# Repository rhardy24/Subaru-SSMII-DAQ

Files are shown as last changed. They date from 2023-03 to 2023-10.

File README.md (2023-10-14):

# Subaru-SSMII-DAQ
A Teensy 4.1 project, interfacing with the SSM Protocol in K-Line based Subarus through the OBD2 port to acquire engine sensor data, display on a TFT LCD, and log to an SD Card

Code is built and uploaded using VSCode and PlatformIO. It currently uses the Arduino framework.

Currently a work in progress

# Overview
In 2008, CAN bus based ISO 15765-4 became stadardized to be used for on-board diagnostics (OBD) in all new vehicles. Prior to this, manufacturers used varying communication protocols and layers for OBD. 

The vehicle this project was designed around is a 2006 Subaru Legacy 2.5i Limited with an EJ253 engine and 4EAT automatic transmission. Although it can vary based of model and region, Subaru's made between 2000 - 2007 used the Subaru Select Monitor II protocol over K-Line (ISO 9141) over the OBD port to communicate with and diagnose the vehicles ECUs. 

Following one of the famous head gasket failures that Subaru's are known for, a method to monitor and log engine sensor data was desired. Thus, this project began.

# Major Components Used
- Teensy 4.1 as the MCU
- Onboard SD slot with SDIO
- Onboard RTC
- [SN65HVDA195QDRQ1 LIN Transceiver](https://www.digikey.ca/en/products/detail/texas-instruments/SN65HVDA195QDRQ1/2094636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)
- [Adafruit 2.8" Capacitive Touchscreen TFT Display](https://www.digikey.ca/en/products/detail/adafruit-industries-llc/2090/9919535)
- [CR2032 Battery Holder](https://www.digikey.ca/en/products/detail/adafruit-industries-llc/1870/6827145) for the RTC
- [Sparkfun OBD2 to DB9 cable](https://www.digikey.ca/en/products/detail/sparkfun-electronics/CAB-10087/5721422)

# Development Notes
Originally, this project was planned to use a Raspberry Pi RP2040 Pico as the MCU, yet after initial testing, it was found that the processor was too slow to achieve a desireable refresh rate on the TFT display. Addionally, there were compatibility issues encountered when testing existing libraries for the TFT display, SD card reader over SPI, and others. With the significantly faster processor, onboard SD and RTC, and broader IO capabilities of the Teensy 4.1, it was chosen as the replacement, with much improved results. 

One issue faced with the Teensy 4.1 was regarding its voltage input. A criteria of the design was to be able to safely plug in / unplug a laptop from the Teensy while it was being powered from the vehicle. There were concerns with shorts when having two devices powering the 5V pin of the Teensy, as it has no on-board circuitry to isolate VUSB from the 5V VIN pin. To solve this, the VUSB jumper on the bottom of the Teensy was cut, which disconnects VUSB from the VIN pin. A female header was soldered to the inboard VUSB through-hole, and a diode was placed between the VUSB pin and VIN. This way, both the laptop and vehicle power coud be connected to the circuit safely. If just the laptop was connected, there would be a small voltage drop across the diode, making the voltage at the VIN pin around 4.3V. When the device was plugged into the vehicle, the LDO would provide 5V to the VIN pin, and no backfeeding would occur between the sources, thanks to the diode. 

## Bugs/To-Dos
- [x] Improve Data receive rate: When requesting ECU data in the single response mode, data would only be received at ~1Hz, which is far less than desireable for fast changing data like engine RPM, timing, MAP, etc. Solved by using the 'respond until interrupted' mode (byte 5 as 0x01 instead of 0x00), and improving efficiency of functions.
- [ ] 12V Supply: The 12V pin on the OBD2 port is always on (KL30), but an ignition power source (KL15) would be more desireable to eliminate the battery draw if the device is left plugged in when the vehicle is off. Need to find a source of switched power to use (while keeping the wiring clean), simply add a power switch that would need to be turned on/off manually with the vehicle ignition, or implement a software sleep state.
- [ ] 5V Regulator: A 7805 LDO (linear dropout) voltage regulator was used to get 5V power for the device, but the large voltage drop across the LDO is undesireable for efficiency and heat. Using a switching regulator circuit in a future iteration would be more desireable, but not mandatory.
- [ ] Log file name with date/time: Incorporate the date/time that the Teensy became powered into the log file name to ensure logs aren't overwritten. This was initially attempted by concatenating Strings into the file name, but caused the Teensy to crash. Also, add date/time back into outputHeaders / outputValues functions
- [ ] Add multiple screens: Use the touchscreen to toggle through multiple screens/gauge layouts. The display is too small to show all of the received data at once, thus multiple display layouts would be nice.
- [ ] Add TCU communication: It would be nice to get information from the transmission controller (TCU), but this is not described in ROMRaider. Research what could be requested from the TCU, and figure out if it is worth sacrificing ECU data rate for.
- [ ] Write script to convert csv data to MoTeC i2 log files: MoTeC i2 is an industry used data viewing software, typically used with MoTeC Motorsport ECUs. Is it possible to convert data into the MoTeC file types to view in i2? Would durastically improve the viewing experience of the logs.
- [ ] Move to an RTOS. Both for the learning, and for proper scheduling and timing of the program, using an RTOS over the Arduino Framework would be a welcomed upgrade to the project.

# References
- Original inspiration for the project: [Obesiance's Clock-pod mod with SSM](https://www.clubwrx.net/threads/clock-pod-mod-with-subarb-select-monitor-ecu-polling-and-arduino.134423369/)
- [RomRaider wiki](https://www.romraider.com/RomRaider/SsmProtocol)
- [rpkish's Subduino-SSM](https://github.com/rpkish/Subduino-SSM)
- [matprophet's subduino](https://github.com/matprophet/subduino)
- [Magister54's opengauge](https://github.com/magister54/opengauge)
- [KrisKasprzak's GraphingFunction](https://github.com/KrisKasprzak/GraphingFunction)

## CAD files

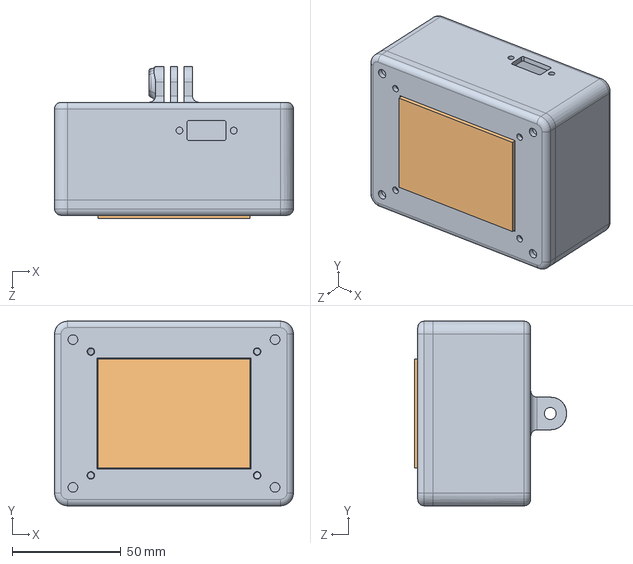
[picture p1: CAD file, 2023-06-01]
CAD-Files/A-001-Top-Level-DAQ.SLDASM
110.0 x 85.0 x 70.0 mm
C-002-Enclosure x 2

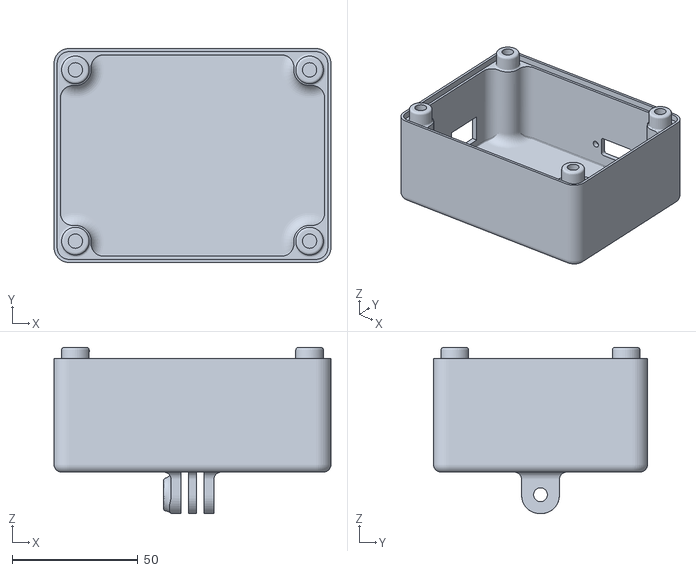
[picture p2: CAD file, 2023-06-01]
CAD-Files/C-002-Enclosure-Bottom-V2.STL
110.0 x 85.0 x 66.0

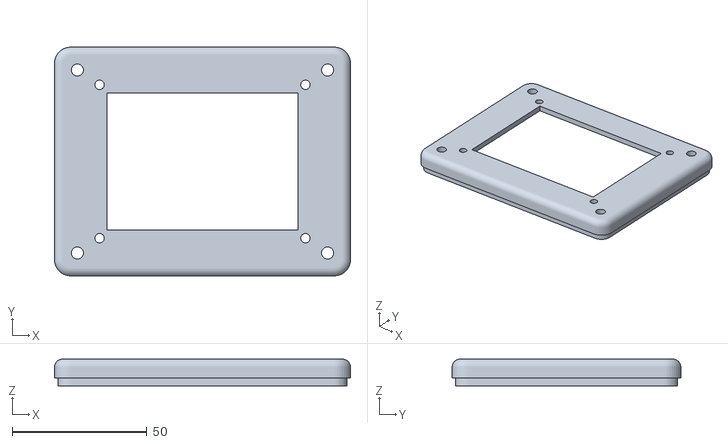
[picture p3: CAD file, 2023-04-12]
CAD-Files/C-002-Enclosure-Top.STL
110.0 x 85.0 x 10.0

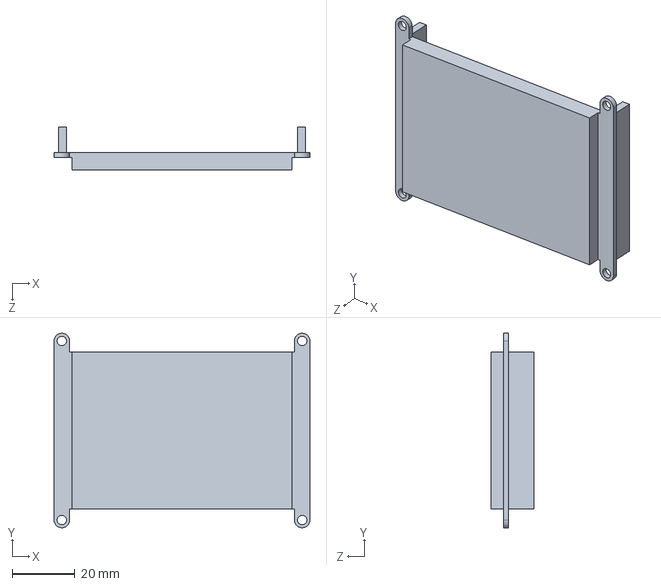
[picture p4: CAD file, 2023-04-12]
CAD-Files/B-001-TFT-Display.SLDPRT
81.5 x 62.0 x 13.6 mm

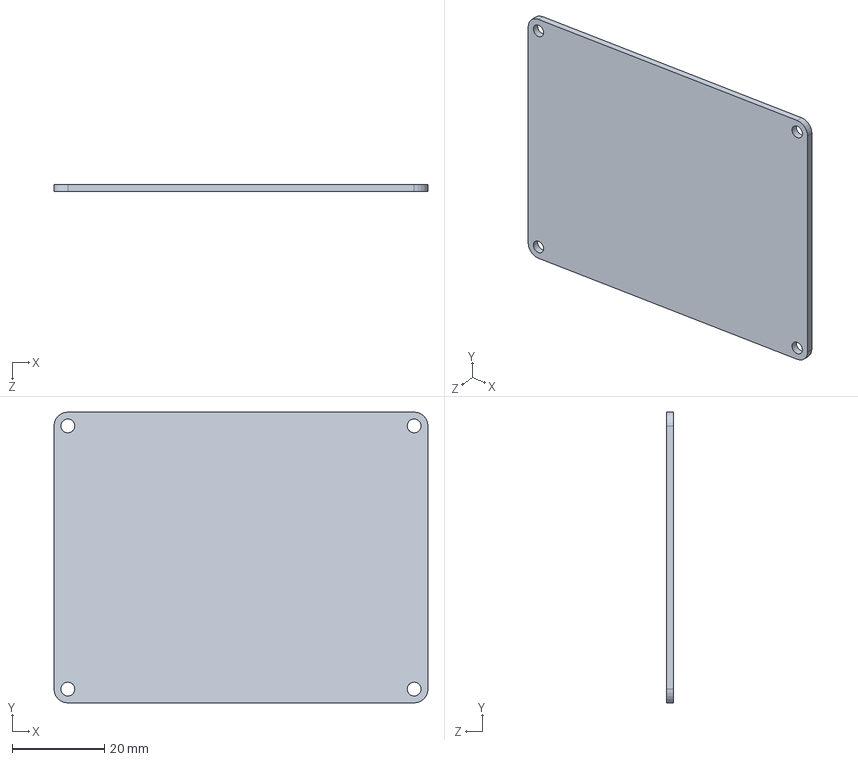
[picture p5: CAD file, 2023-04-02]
CAD-Files/C-001-PCB.SLDPRT
81.0 x 63.0 x 1.60 mm

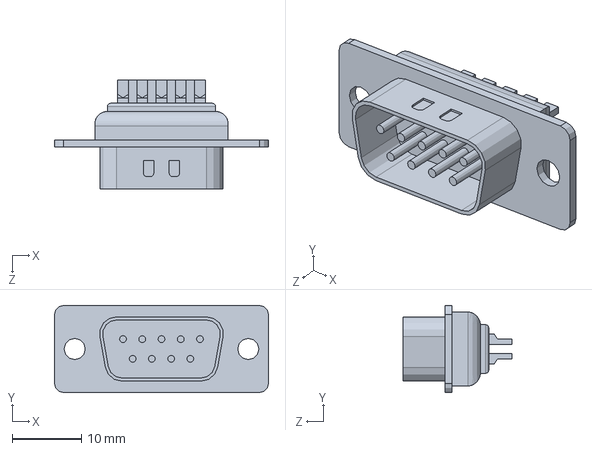
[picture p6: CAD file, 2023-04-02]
CAD-Files/B-002-DB9M.SLDPRT
30.8 x 12.6 x 15.8 mm

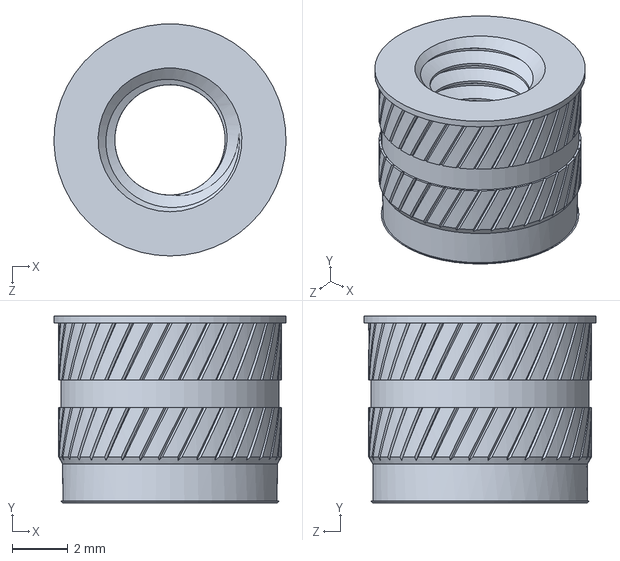
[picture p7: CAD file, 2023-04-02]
CAD-Files/B-011-M5-Barb.SLDPRT
8.33 x 6.70 x 8.32 mm

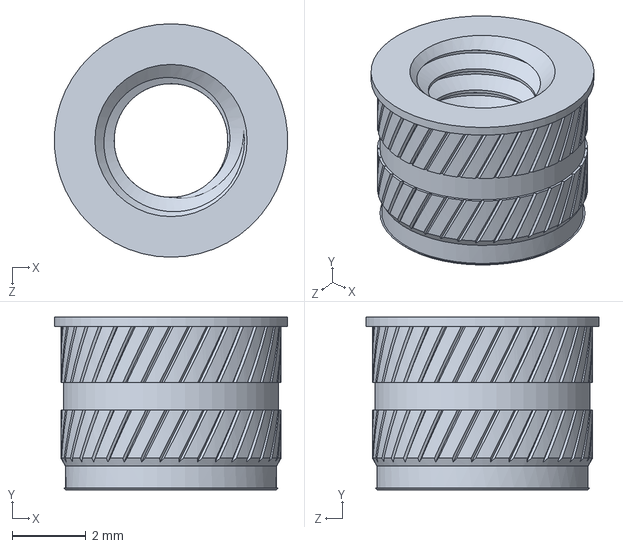
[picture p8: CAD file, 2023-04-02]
CAD-Files/B-010-M4-Barb.SLDPRT
6.34 x 4.70 x 6.35 mm

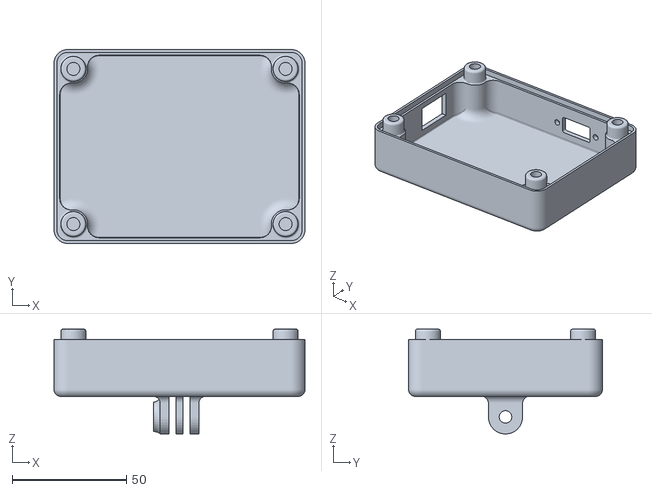
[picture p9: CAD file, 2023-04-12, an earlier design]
CAD-Files/C-002-Enclosure-Bottom.STL
110.0 x 85.0 x 46.0

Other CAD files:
CAD-Files/C-002-Enclosure.SLDPRT

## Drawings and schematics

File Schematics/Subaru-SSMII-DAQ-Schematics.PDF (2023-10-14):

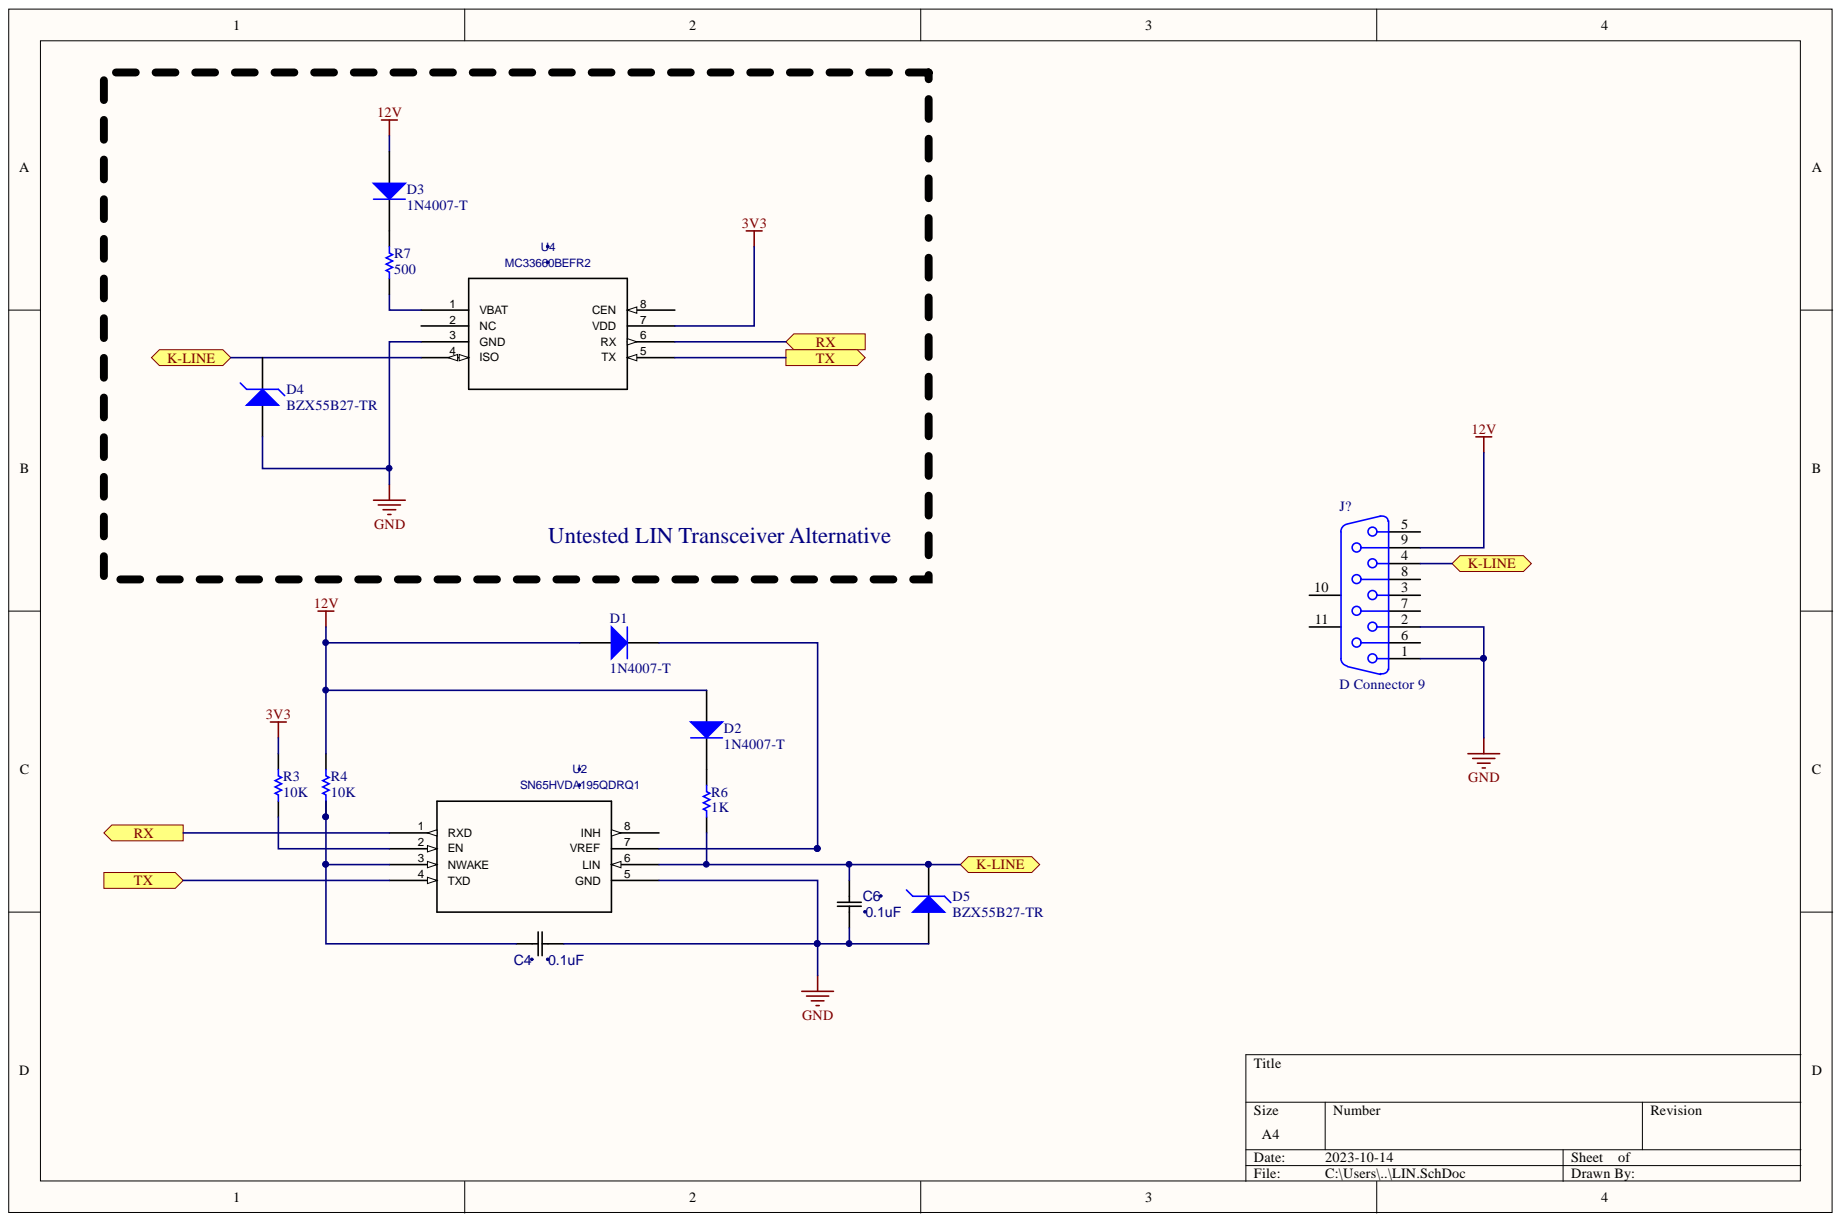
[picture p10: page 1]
Sheet o; 5 ISO; GND 3; VBAT 1; Untested LIN; Transceiver Alternativ

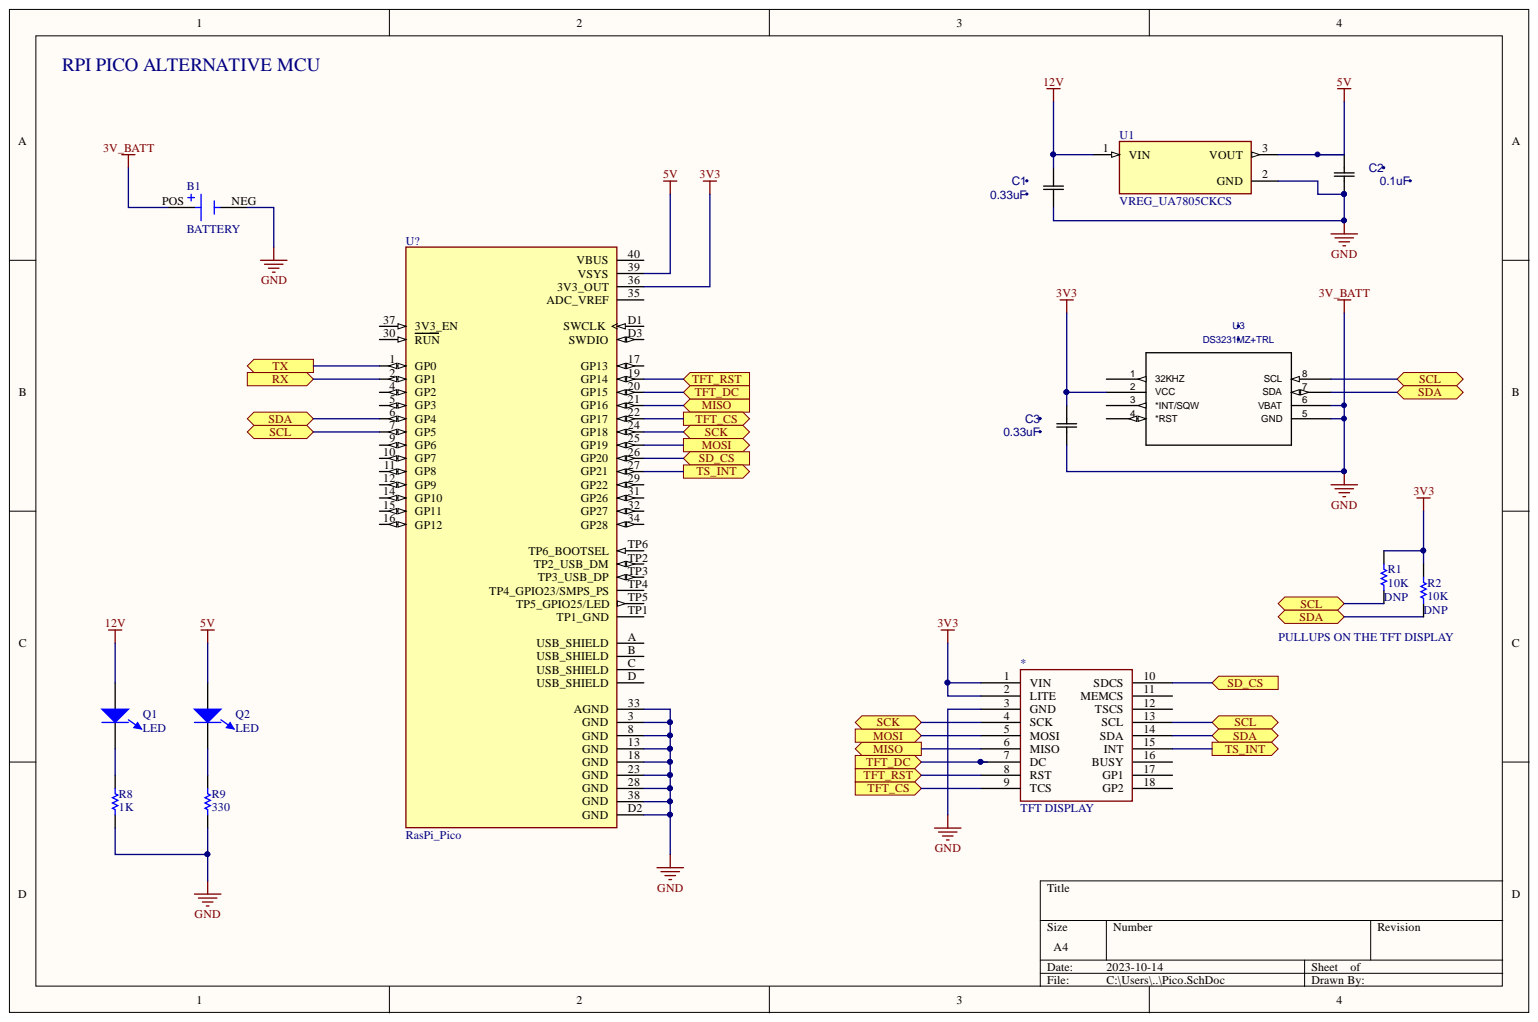
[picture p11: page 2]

1 3
1 8
2 3
2 8
3 8
D 2

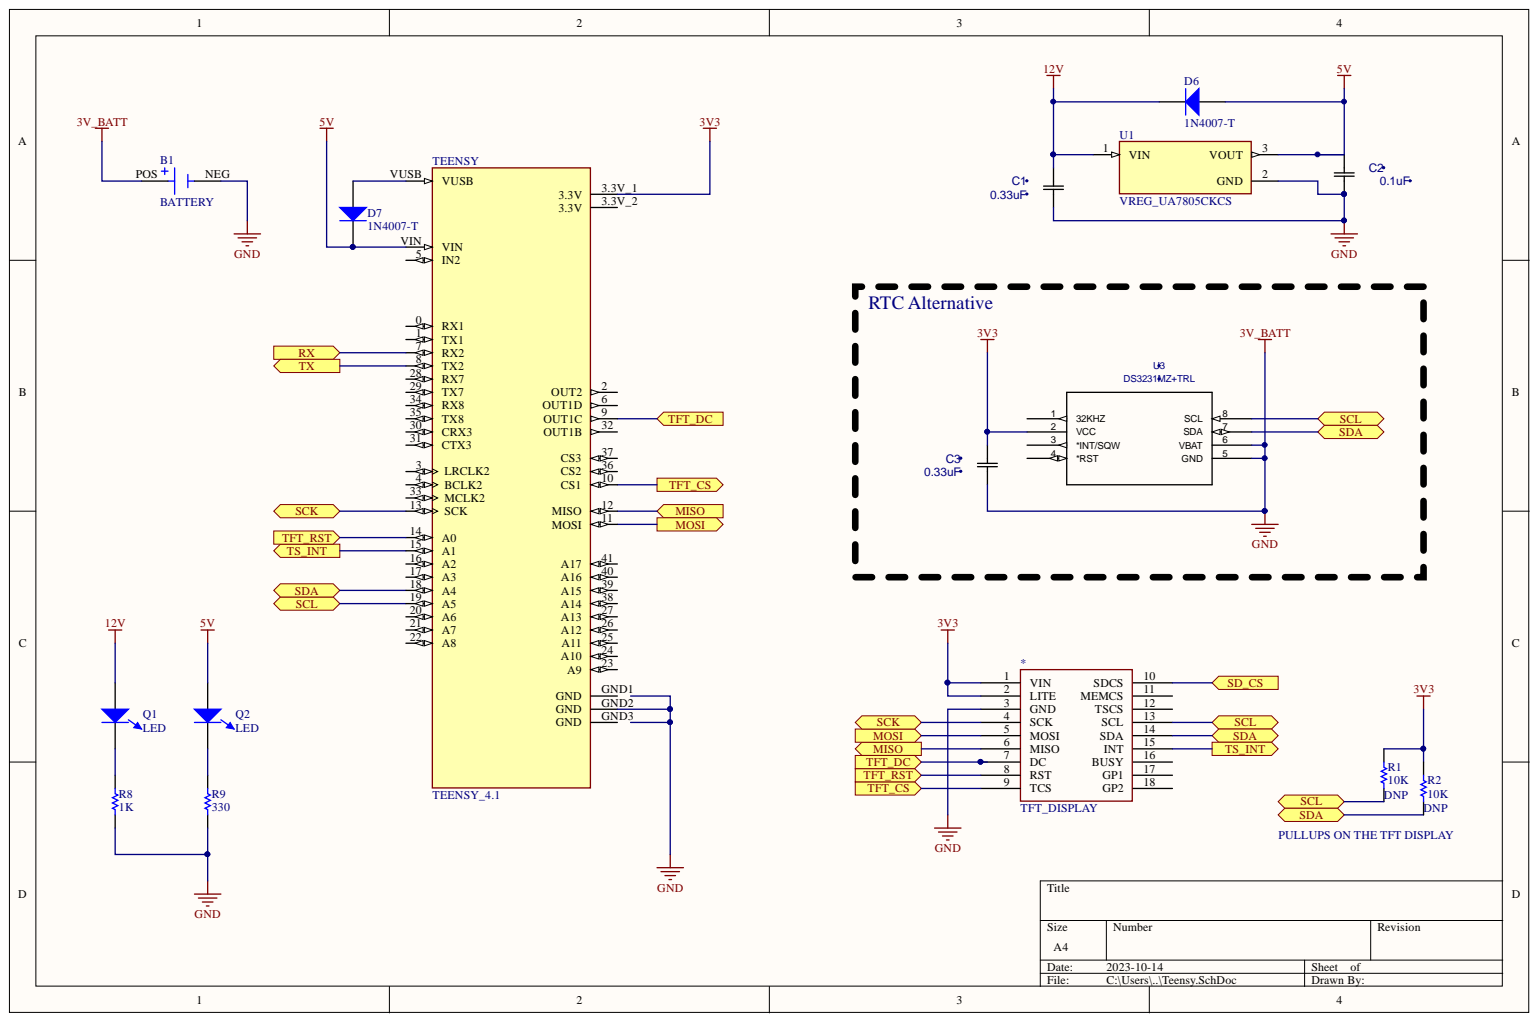
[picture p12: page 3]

LITE 2
GND 3
SCK 4 MOSI 5 MISO 6 DC 7 RST 8 TCS 9

SCL
SDA
PULLUPS ON THE TFT DISPLAY

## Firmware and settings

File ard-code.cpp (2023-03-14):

// 06 SpecB Rom ID
// 4512783106

// Clutch and Brake Switch Info
// 72  (0x48) [01001000] = Brake On
// 128 (0x80) [10000000] = Clutch On
// 200 (0xC8) [11001000] = Both On

// Can Stuff
#include <Arduino.h>

#define SINGLE_REQ
#define INTERPRET
#define LOG
#define USE_DISPLAY

#ifdef LOG
  #include <SD.h>
  #define chipSelect BUILTIN_SDCARD
  File logFile;
#endif

#ifdef USE_DISPLAY
  #include <SPI.h>
  #include <Adafruit_ILI9341.h>

  boolean graph_1 = true;
  boolean graph_2 = true;
  boolean graph_3 = true;

  #define LTBLUE    0xB6DF
  #define LTTEAL    0xBF5F
  #define LTGREEN         0xBFF7
  #define LTCYAN    0xC7FF
  #define LTRED           0xFD34
  #define LTMAGENTA       0xFD5F
  #define LTYELLOW        0xFFF8
  #define LTORANGE        0xFE73
  #define LTPINK          0xFDDF
  #define LTPURPLE  0xCCFF
  #define LTGREY          0xE71C
  
  #define BLUE            0x001F
  #define TEAL    0x0438
  #define GREEN           0x07E0
  #define CYAN          0x07FF
  #define RED           0xF800
  #define MAGENTA       0xF81F
  #define YELLOW        0xFFE0
  #define ORANGE        0xFD20
  #define PINK          0xF81F
  #define PURPLE    0x801F
  #define GREY        0xC618
  #define WHITE         0xFFFF
  #define BLACK         0x0000
  
  #define DKBLUE        0x000D
  #define DKTEAL    0x020C
  #define DKGREEN       0x03E0
  #define DKCYAN        0x03EF
  #define DKRED         0x6000
  #define DKMAGENTA       0x8008
  #define DKYELLOW        0x8400
  #define DKORANGE        0x8200
  #define DKPINK          0x9009
  #define DKPURPLE      0x4010
  #define DKGREY        0x4A49
  
  #define TFT_DC 9
  #define TFT_CS 10
  #define TFT_MOSI 11
  #define TFT_CLK 13
  #define TFT_RST 14
  #define TFT_MISO 12

  Adafruit_ILI9341 tft = Adafruit_ILI9341(TFT_CS, TFT_DC, TFT_MOSI, TFT_CLK, TFT_RST, TFT_MISO);
#endif

//int ECUbytes[11] = {};
int ECUbytes[16] = {};

/*                                      |rpm - 2 bytes| tmp |  spd |  swt | gear   | tps |
byte ReqData[28] = {128,16,240,23,168,0,0,0,15,0,0,14,0,0,8,0,0,16,0,1,33,255,83,5,0,0,21,2}; // add throttle
                  //80,10,f0,17,a8,0,0,0,f,0,0,e,0,0,8,0,0,10,0,1,21,ff,53,5,0,0,15,2
byte ReqDataSize = 28;
*/
byte capBitsReq[6] = {0x80, 0x10, 0xf0, 0x01, 0xBF, 0x40}; 
byte capBitsReqSize = 6;


//subtract 40 from decomal value for deg C
//byte coolTempReq[22] = {0x80, 0x10, 0xf0, 0x11, 0xa8, 0x00, 0x00, 0x00, 0x08, 0x00, 0x00, 0x0D, 0x00, 0x00, 0x0E, 0x00, 0x00, 0x0f, 0x00, 0x00, 0x10, 0x7b}; //7 byte response expected
//ECT, MAP, IAT, TPS, VOLT

#ifdef SINGLE_REQ
  byte coolTempReq[37] = { 0x80, 0x10, 0xf0, 0x20, 0xa8, 0x01, 
                        0x00, 0x00, 0x08, 0x00, 0x00, 0x0D, 0x00, 0x00, 0x0E, 0x00, 0x00, 0x0F, 0x00, 0x00, 0x10, 
                        0x00, 0x00, 0x11, 0x00, 0x00, 0x12, 0x00, 0x00, 0x15, 0x00, 0x00, 0x1c, 0x00, 0x00, 0x2a, 
                        0x09};
                        
  //byte coolTempReq[22] = {0x80, 0x10, 0xf0, 0x11, 0xa8, 0x01, 0x00, 0x00, 0x08, 0x00, 0x00, 0x0D, 0x00, 0x00, 0x12, 0x00, 0x00, 0x15, 0x00, 0x00, 0x1c, 0x92}; //7 byte response expected
#else
  byte coolTempReq[22] = {0x80, 0x10, 0xf0, 0x11, 0xa8, 0x00, 0x00, 0x00, 0x08, 0x00, 0x00, 0x0D, 0x00, 0x00, 0x12, 0x00, 0x00, 0x15, 0x00, 0x00, 0x1c, 0x91}; //7 byte response expected
#endif


//byte coolTempReqSize = 22;
byte coolTempReqSize = 37;
/*
byte coolTempReq[37] = { 0x80, 0x10, 0xf0, 0x20, 0xa8, 0x00, 
                        0x00, 0x00, 0x08, 0x00, 0x00, 0x0D, 0x00, 0x00, 0x0E, 0x00, 0x00, 0x0F, 0x00, 0x00, 0x10, 
                        0x00, 0x00, 0x11, 0x00, 0x00, 0x12, 0x00, 0x00, 0x15, 0x00, 0x00, 0x1c, 0x00, 0x00, 0x2a, 
                        0x08}; //7 byte response expected
*/
//22d without address with 5 size
//Expected response: 0x80, 0xf0, 0x10, 0x2, 0xe8, 0x28, 0x(check)   (for 0 deg C)

//multiply decimal value by 0.08
byte batVoltReq[10] = {0x80, 0x10, 0xf0, 0x05 , 0xa8, 0x00, 0x00, 0x00, 0x1c, 0x49};
byte batVoltReqSize = 10;
//Expected response: 0x80, 0xf0, 0x10, 0x2, 0xe8, 0x9c, 0x(check)

typedef struct{
  double ECT;
  double MAP;
  double RPM;
  double speedkm;
  double timing;
  double IAT;
  double TPS;
  double BATVOLT;
  double EFT;
} ECU_Data;
ECU_Data interpretted_data = {};

int SerialStatus=0;
int milli;
int ClrToSnd;


//byte ReqData[13] = {128,16,240,8,168,0,0,0,15,0,0,14,77};
//byte ReqDataSize = 13;
int readDelay = 2;
unsigned long prvTime;
unsigned long prvReadTime;
unsigned long curTime;

void setup()
{
  Serial.begin(115200); //for diagnostics
    while (!Serial) {
      // wait
    }
  Serial.println("Connecting to Serial");
  Serial2.begin(4800); //SSM uses 4800 8N1 baud rate
    while (!Serial2) {
      //wait
      delay(50);
  }
  Serial.println("Serial Line Established");
  Serial.println("Setup Complete");
  delay(50);
  /*
  writeSSM(capBitsReq, capBitsReqSize, Serial2);
  Serial2.flush();
  delay(500);
  */

  #ifdef LOG
    if (!SD.begin(chipSelect)) {
      Serial.println("SD initialization failed!");
    }
    else
      Serial.println("SD Initialized");
    logFile = SD.open("log.txt", FILE_WRITE);
   
    if(logFile)
      Serial.println("File opened");
    else
      Serial.println("File open failed");
  
    outputHeaders(logFile);
    logFile.flush();
  #endif

  #ifdef USE_DISPLAY
    tft.begin();
    tft.fillScreen(BLACK);
    tft.setRotation(1);
  #endif
  
  #ifdef SINGLE_REQ
    delay(500);
    writeSSM(coolTempReq, coolTempReqSize, Serial2);
  #endif
  
  delay (2);
}

bool responseGood = 0;

void loop()
{
curTime = millis();
milli=curTime - prvTime;  
Serial.println("Loop ");
delay(10);

//if (milli > 250) {
if(true){
  Serial2.flush(); //waits for serial out buffer to empty (everything sent)
  //delay(5);
  //writeSSM(ReqData, ReqDataSize, Serial2);
  
  #ifndef SINGLE_REQ
    writeSSM(coolTempReq, coolTempReqSize, Serial2);
  #endif
  
  //Serial.println("Timer Popped");
  prvTime=millis();
  }

  if (Serial2.available()) {  
    Serial.println();
    responseGood = readECU(ECUbytes, false);
    /*if(!responseGood){
      while(Serial2.available()){
        if( (Serial2.peek()) != 0x80){
           Serial2.read();
        }
        Serial.println("flushing");
      }
    }*/

    if(!responseGood){
      //Serial2.flush();
      Serial2.end();
      Serial2.begin(4800);
      Serial.println("Flushed");
    }
    
    Serial.print("Response Good: ");
    Serial.println(responseGood);
    
    prvTime = curTime;
    
    //if(responseGood){
    if(true){
      Serial.print("ECU bytes: ");
      for (int i = 0; i < sizeof(ECUbytes)/sizeof(int); i++){
        Serial.print(String(ECUbytes[i], HEX));
        Serial.print(",");
      }
      #ifdef INTERPRET
        if(responseGood){
          interpretData(&interpretted_data, ECUbytes);
          Serial.println();
          outputHeaders(Serial);
          outputValues(Serial, &interpretted_data);
          #ifdef LOG
            outputValues(logFile, &interpretted_data);
            logFile.flush();
          #endif
          #ifdef USE_DISPLAY
            DrawBarChartV(tft, 10,  210, 30, 180, 0, 100 , 10, interpretted_data.TPS , 3 , 1, BLUE, DKBLUE, BLUE, WHITE, BLACK, "TPS", graph_1);
            DrawBarChartH(tft, 100, 180, 150, 30, 0, 20, 2, interpretted_data.MAP, 2, 2, GREEN, DKGREEN,  GREEN, WHITE, BLACK, "MAP", graph_2);
            DrawDial(tft, 230, 90, 80, 0, 7000 , 500, 240, interpretted_data.RPM,  4 , 0, RED, WHITE, BLACK, "RPM", graph_3);
          #endif
          }
      #endif
      Serial.println();
    }
    
    //delay(20);    
  }
  else{
    delay(100);
    Serial.println("Serial 2 unavailable");
  }
    

  #ifdef SINGLE_REQ
    if ((curTime - prvReadTime) > 50){
      writeSSM(coolTempReq, coolTempReqSize, Serial2);
      prvReadTime = millis();
      //readECU(ECUbytes, false);
    }
      
    if (responseGood)
      prvReadTime = millis();
  #else
    if (ClrToSnd == 0) {
      //writeSSM(ReqData, ReqDataSize, Serial2);
      writeSSM(coolTempReq, coolTempReqSize, Serial2);
      ClrToSnd = 1;
      Serial2.flush();
      Serial2.end();
      Serial2.open(4800);
    }
  #endif

  //delay(250);
}

/* returns the 8 least significant bits of an input byte*/
byte CheckSum(byte sum) {
  byte counter = 0;
  byte power = 1;
  for (byte n = 0; n < 8; n++) {
    counter += bitRead(sum, n) * power;
    power = power * 2;
  }
  return counter;
}

/*writes data over the software serial port
the &digiSerial passes a reference to the external
object so that we can control it outside of the function*/
void writeSSM(byte data[], byte length, Stream &digiSerial) {
  Serial.print(F("Sending packet... "));
  for (byte x = 0; x < length; x++) {
    digiSerial.write(data[x]);
    Serial.print(String(data[x],HEX));
    Serial.print(",");
  }
  digiSerial.flush();
  Serial.println();
}

//this will change the values in dataArray, populating them with values respective of the poll array address calls
boolean readECU(int* dataArray, boolean nonZeroes)
{
  byte data = 0;
  boolean isPacket = false;
  byte sumBytes = 0;
  byte checkSumByte = 0;
  byte dataSize = 0;
  byte bytePlace = 0;
  byte zeroesLoopSpot = 0;
  byte dataArrayLength = sizeof(dataArray)/sizeof(int);
  byte loopLength = 20;
  for (int i = 0; i < sizeof(dataArray)/sizeof(int); i++)
    dataArray[i] = 9999;
  for (byte j = 0; j < loopLength; j++)
  //for (byte j = 0; j < sizeof(dataArray)/sizeof(int); j++)
  {
    data = Serial2.read();
    Serial.print(String(data,HEX));
    Serial.print(", ");
    delay(readDelay);
    dataArray[bytePlace] = data;

    if (data == 128 && dataSize == 0) { //0x80 or 128 marks the beginning of a packet
      isPacket = true;
      j = 0;
      //Serial.println("Begin Packet");
    }

    //terminate function and return false if no response is detected
    if (j == (loopLength - 1) && isPacket != true)
    {
      return false;
    }

    if (isPacket == true && data != -1) {
  //    Serial.print(data); // for debugging: shows in-packet data
  //    Serial.print(" ");

      if ( (bytePlace == 0 && data != 0x80) || (bytePlace == 1 && data != 0xf0) || (bytePlace == 2 && data != 0x10) ){
        Serial.println("Bad start of read");
        return false;
      }
        

      if (bytePlace == 3) { // how much data is coming
        dataSize = data;
        loopLength = data + 6;
        if (loopLength > 20){
          Serial.println("Loop length too long");
          return false;
        }
          
      }

      if (bytePlace > 4 && bytePlace - 5 < dataArrayLength && nonZeroes == false)
      {
        //dataArray[bytePlace - 5] = data;
      }
      else if (bytePlace > 4 && zeroesLoopSpot < dataArrayLength / 2 && nonZeroes == true && data != 0 && bytePlace < dataSize + 4)
      {
        //dataArray[zeroesLoopSpot] = data;
        //dataArray[zeroesLoopSpot + (dataArrayLength / 2)] = bytePlace;
        zeroesLoopSpot++;
      }

      bytePlace += 1; //increment bytePlace

      //once the data is all recieved, checksum and re-set counters
     // Serial.print("byte place: ");
     // Serial.println(bytePlace);
      if (bytePlace == dataSize + 5) {
        checkSumByte = CheckSum(sumBytes);  //the 8 least significant bits of sumBytes

        if (data != checkSumByte) {
          Serial.println(F("checksum error"));
          Serial.print("Loop Length: ");
          Serial.println(loopLength);
          return false;
        }
//        Serial.println("Checksum is good");
/*
        ClrToSnd = 0;
        isPacket = false;
        sumBytes = 0;
        bytePlace = 0;
        checkSumByte = 0;
        dataSize = 0;
*/
        Serial.print("Loop Length: ");
        Serial.println(loopLength);
        return true;
      }
      else {
        sumBytes += data; // this is to compare with the checksum byte
        //Serial.print(F("sum: "));
        //Serial.println(sumBytes);
      }
    }
  }
  
}

/*************************************************************************
 * LEFT-OFF HERE IN THE CODE CONVERSION
**************************************************************************/

bool interpretData(ECU_Data* interpData, int* rawArray){
  if(rawArray[1] != 0xf0) //ignore anything that isn't being sent to the diagnostic tool (us)
    return false;
  
  interpData->ECT = rawArray[5]-40;        //deg C
  interpData->MAP = rawArray[6]*37.0/255;    //absolute PSI
  interpData->RPM = (rawArray[8] | (rawArray[7] << 8))/4.0;    //RPM
  interpData->speedkm = rawArray[9];         //km/h
  interpData->timing = (rawArray[10]-128)/2.0;     //degrees BTDC
  interpData->IAT = rawArray[11]-40;       //deg C
  interpData->TPS = rawArray[12]*100/255.0;  //percent
  interpData->BATVOLT = rawArray[13]*0.08; //volt
  interpData->EFT = rawArray[14]-40;       //deg C
  return true;
}

void outputHeaders(Stream &outStream){
  outStream.println("RPM\tSpeed\tTPS\tMAP\tTiming\tECT\tIAT\tEFT\tVoltage");
}

void outputValues(Stream &outStream, ECU_Data* data){
  outStream.println();
  outStream.print(data->RPM);

  outStream.print("\t");
  outStream.print(data->speedkm);

  outStream.print("\t");
  outStream.print(data->TPS);

  outStream.print("\t");
  outStream.print(data->MAP);

  outStream.print("\t");
  outStream.print(data->timing);

  outStream.print("\t");
  outStream.print(data->ECT);

  outStream.print("\t");
  outStream.print(data->IAT);

  outStream.print("\t");
  outStream.print(data->EFT);

  outStream.print("\t");
  outStream.print(data->BATVOLT);
}
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

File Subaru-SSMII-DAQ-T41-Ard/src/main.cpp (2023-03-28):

#include <Arduino.h>

#include <gauge_tft.h>
#include <sd_logger.h>
#include <subaru_ssm.h>

#include <config.h>

void setup() {
  #ifdef DEBUB
    Serial.begin(SERIAL_MONITOR_BAUD);
    while(!Serial)
      delay(10);
  #endif

  loggerBegin();
  gaugesBegin();

  delay(250);

  ssmBegin();
}

void loop() {
  receiveECUdata();
  logCurrentValues(logFile, &interpretted_data);
  updateGauges(&interpretted_data, 1);
}

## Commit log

2023-03-13 Update README.md
    Update README for software framework being used
2023-03-13 Library files created, conversion from bad Arduino code started
2023-03-14 Continuing to convert/clean test Arduino code to full program
2023-03-14 Finishing porting over arduino test code, fully compiled, untested
2023-03-15 Cleaned up working code, removed fragments from failed testing, made define statement for debug messages to speed up loop when they're not needed
    [main.cpp]
2023-03-28 Started CAD, added LCD
    [B-001-TFT-Display.SLDPRT]
2023-04-02 More CAD added, enclosure started
    [B-001-TFT-Display.SLDPRT, B-002-DB9M.SLDPRT, B-010-M4-Barb.SLDPRT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]
2023-04-12 CAD: Finsihed V1 enclosure
    [B-001-TFT-Display.SLDPRT, C-002-Enclosure.SLDPRT]
2023-04-12 CAD: File creation
    [A-001-Top-Level-DAQ.SLDASM, C-002-Enclosure-Bottom.STL, C-002-Enclosure-Top.STL]
2023-06-01 Increased depth of enclosure to fit all electronics
    [A-001-Top-Level-DAQ.SLDASM, C-002-Enclosure.SLDPRT]
2023-06-01 V2 Bottom Enclosure, 20mm deeper inside
    [C-002-Enclosure-Bottom-V2.STL]
2023-10-14 Added project schematics
    [AltiumV15.PcbLib, AltiumV15.SchLib, LIN.SchDoc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]
